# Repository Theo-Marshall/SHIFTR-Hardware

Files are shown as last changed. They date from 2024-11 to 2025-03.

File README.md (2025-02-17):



# SHIFTR 
A BLE to Direct Connect bridge for bike trainers using a WT32-ETH01 module based on ESP32. Increases connection stability and additionally adding Zwift "virtual shifting" functionality to any device supporting FE-C over BLE. Also adding FTMS emulation via DirCon for non-FE-C compatible software like MyWhoosh.

Currently tested with Garmin/Tacx NEO 2T and Vortex but should also work on other trainers supporting FE-C over BLE.

Tested bike trainer software so far:
- &#x2611; Zwift (Pass-through + virtual shifting mode)
- &#x2611; MyWhoosh (Pass-through mode only / TACX Neo 2T and Vortex only with FTMS emulation enabled) 

Disclaimer: Even if everything is working fine this project is still work in progress. Feel free to provide feedback if you encounter any issues.

## Overview
Bike trainers heavily evolved over the last few years. Tacx (acquired by Garmin some years ago) is one of the market leaders producing bike trainers of a very high quality with special features like e.g. "Road Feeling" to simulate different road surfaces. 
Other vendors like Zwift came up with cool new features like "virtual shifting" using the "Zwift Cog" and a controller device (Zwift Click/Play) to have a non-mechanical shifting solution which is setting the gears via software that adjusts the resistance in the trainer. 
Wahoo came up with a technology called "Direct Connect" that allows the trainer devices to be connected via Ethernet (or even WiFi) instead of bluetooth to have a more stable connection.

While other vendors like e.g. Elite or JetBlack are very fast in implementing things like virtual shifting to their newer models Garmin is very slow and unresponsive when it comes to such feature requests. Probably also because they have their own ecosystem that competes with Zwift. 

Using Zwift for many years and owning a "Tacx Vortex" and a "Tacx Neo 2T" bike trainer I have been jealous of features like virtual shifting and the possibility to connect the trainer device via ethernet. So the idea for this project, SHIFTR, was born by having a device between Zwift and the Tacx supporting all this cool new functionality.

After many days and nights of searching the internet for a specification of the protocols I was only able to find small parts for "Direct Connect" that have already been reverse engineered by Roberto Viola in his [QDomyos-Zwift](https://github.com/cagnulein/qdomyos-zwift) project. The code helped me a lot to understand the protocol.
Unfortunately there was absolutely no information about the "virtual shifting" to be found. So a very long session of decompiling Zwift apps and sniffing BLE traffic between Zwift and capable trainers (which fortunately a friend had one of) started. It took some weeks but I was able to reverse engineer the used protocols.

As I wanted to have a convenient solution that doesn't require a special program or app to be started to have that functionality I decided to implement everything on an ESP32 microcontroller that already features WiFi and Bluetooth onboard and also optionally ethernet. The perfect module for that was the [WT32-ETH01](https://en.wireless-tag.com/product-item-2.html) module that comes with everything I needed. The device will be placed very close to the trainer in a 3D printed case that also has a place for a step down converter to be able to use the existing power supply from the trainer.

Now I have a great setup with a Garmin/Tacx NEO 2T with a Zwift Cog installed and communicating to Zwift via ethernet while still having the "Road Feeling" feature: 
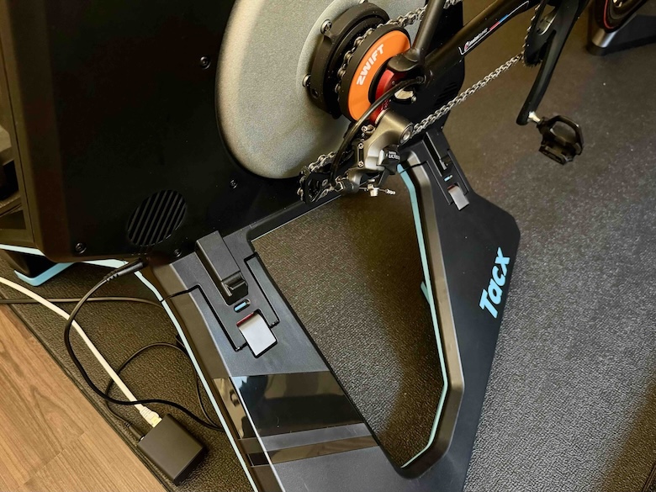
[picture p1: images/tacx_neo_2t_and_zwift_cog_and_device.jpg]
The whole setup


This setup even works great with Zwift running on an Apple TV. Apple TV only supports two simultaneous bluetooth connections and those can now be used for the Zwift Play controllers while the trainer itself is being connected through ethernet.

## How it works
The SHIFTR is working in two modes, "Pass-through" and "Pass-through + virtual shifting":
### Pass-through mode
In this mode the SHIFTR just takes all services from the BLE trainer devices and provides them 1:1 via Direct Connect. It supports SIM and ERG mode as if the device would be connected via bluetooth.
### Pass-through + virtual shifting mode
This mode provides the pass through features as mentioned before and additionally offers a special Zwift service via Direct Connect that allows it to behave like a Zwift certified device offering virtual shifting, too. All necessary information like incline, bicycle and user weight, etc. are transmitted by Zwift and used for calculations. SIM and ERG mode are supported but of course virtual shifting only works in SIM mode.

Details about the virtual shifting function and calculations can be found [here](./VirtualShifting.md).

***Note***: Virtual shifting will be disabled if neither Zwift Play controllers nor a Zwift Click are connected which results in the standard SIM mode with a track resistance of 0%. Then you'd have to shift with your bike but with a Zwift Cog installed this doesn't make sense of course. If the controllers disconnect during a training then the fallback will be this normal SIM mode but as soon as the controller(s) are re-connected the virtual shifting will be enabled again.

### Pass-through + FTMS emulation
This mode provides all services from the BLE trainer and additionally offers a FTMS emulation that internally sends the commands to the BLE FE-C trainer. This makes software like MyWhoosh also working. Doesn't (at least not yet) work with virtual shifting as this is a Zwift-only feature at the moment.

## Needed hardware
- WT32-ETH01 ESP32 board (e.g. from [Amazon](https://www.amazon.de/WT32-ETH01-Embedded-Schnittstelle-Bluetooth-Entwicklungsplatine/dp/B0CW3DDWZ4))
- Step-Down converter 5-80V (the Tacx Neo supplies 48V) to 5V (e.g. from [Amazon](https://www.amazon.de/dp/B0CMC7Y3DJ))
- Y-Splitter for the Tacx power cable (e.g. from [Amazon](https://www.amazon.de/dp/B09FHHN9T5))
- Power connector for the case (e.g. from [Amazon](https://www.amazon.de/gp/product/B09PD6J4BN))
- 3D printed case that fits the WT32-ETH01. Luckily I was able to find a perfect match that also fits the step-down converter: [WT32-ETH01 Enclosure](https://www.thingiverse.com/thing:5621092)
- Two countersunk screws M2x7 to hold the lid on the case

## Hardware installation
- ***IMPORTANT***: Don't solder the pin headers that came with the WT32-ETH01. With the longer pins on the bottom side the module won't fit the case anymore.
- ***IMPORTANT #2***: Connect the step-down converter first to a power supply (e.g. the original one with 48V) and a multimeter and use a screwdriver to adjust the output voltage to 5V before connecting it to the WT32-ETH01 module!
- Use a standard USB<->TTL converter (e.g. with FTDI232 or similar). Make sure that it can provide **3,3V and not 5V** and connect as follows (see also pinout above):
  | Converter | -> | ETH01-EVO | 
  |-|-|-|
  | RX | -> | TXD |
  | TX | -> | RXD |
  | 3V3 | -> | 3V3 |
  | GND | -> | GND |

  It's best to use some breadboard jumper wires that can just be connected without soldering. Use a rubber band to hold them in contact.

  To start the WT32-ETH01 in boot mode it is necessary to connect "IO0" with GND and then to reset the board, shortly connect "EN" to GND for a quarter of a second.

## Software installation
- Open the project in [PlatformIO](https://platformio.org) and let it install the dependencies
- Connect the programmer and upload via the task wt32-eth01 -> Upload and Monitor
- Connect an ethernet cable and make sure a DHCP server exists in your network
- After a few seconds you should be able to see the IP address and the hostname (like e.g. "SHIFTR-123456.local") in the monitor log
- If you don't use the Ethernet interface you can also use the WiFi functionality. For that the device opens an AP with the device name (e.g. "SHIFTR-123456") and the password is the same but of course can be changed later. Please note that WiFi is provided by an external library called [IoTWebConf](https://github.com/prampec/IotWebConf) and is more or less untested
- After that you can configure the device and its network settings in the web interface on e.g. http://SHIFTR-123456.local
- The status page is accessible without credentials, the settings and firmware update pages need the username "admin" and the password is the configured AP password or just the device name (e.g. "SHIFTR-123456") as default. Note that both are case sensitive!
- Further updates can be made over ethernet or WiFi so you can disconnect the programming adapter now

## Finalization
- Finally you can solder some wires to the power connector to the step down module and from there to the WT32-ETH01. Then mount everything in the 3D printed case:

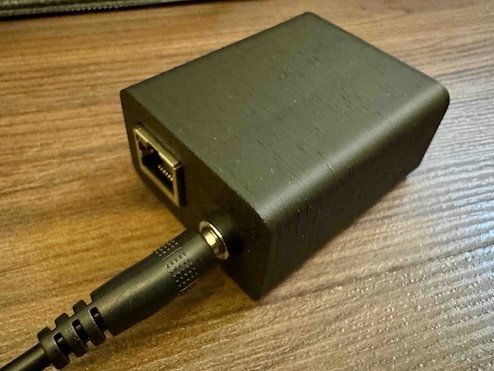
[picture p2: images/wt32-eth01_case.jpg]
Mounted adapter
  

- Use the Y-Power-Splitter to connect the Tacx trainer and the device:
  
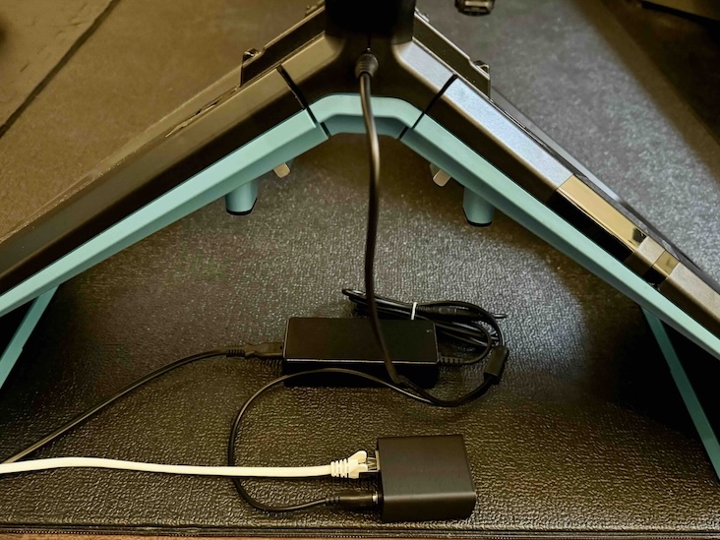
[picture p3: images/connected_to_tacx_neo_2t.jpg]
Connected to Tacx
  

- Power the Trainer and go to the web interface
- Go to "Settings", select the trainer device and "Save"
- Make sure the "Virtual shifting" option is enabled if you want to use it. Virtual shifting only works in Zwift when a Zwift Click or Zwift Play controllers are connected. Otherwise it will fall back to the normal ERG and SIM modes
- In Zwift you need to connect to the "SHIFTR 123456" device instead of your old device now. Have fun!

## Thank you!
You've made it to the end, hopefully you'll have fun rebuilding the whole thing. Please tell me if you like it and if it works as expected.
In case of any questions feel free to contact me!

## Disclaimer
Please always check the documentation of the hardware you bought as there are sometimes small changes in pin assignments, voltage and so on. I don't take any liability for damages or injuries. Build this project at your own risk. The linked products and pages are for reference only. I don't get any money from the manufacturers or the (re)sellers.

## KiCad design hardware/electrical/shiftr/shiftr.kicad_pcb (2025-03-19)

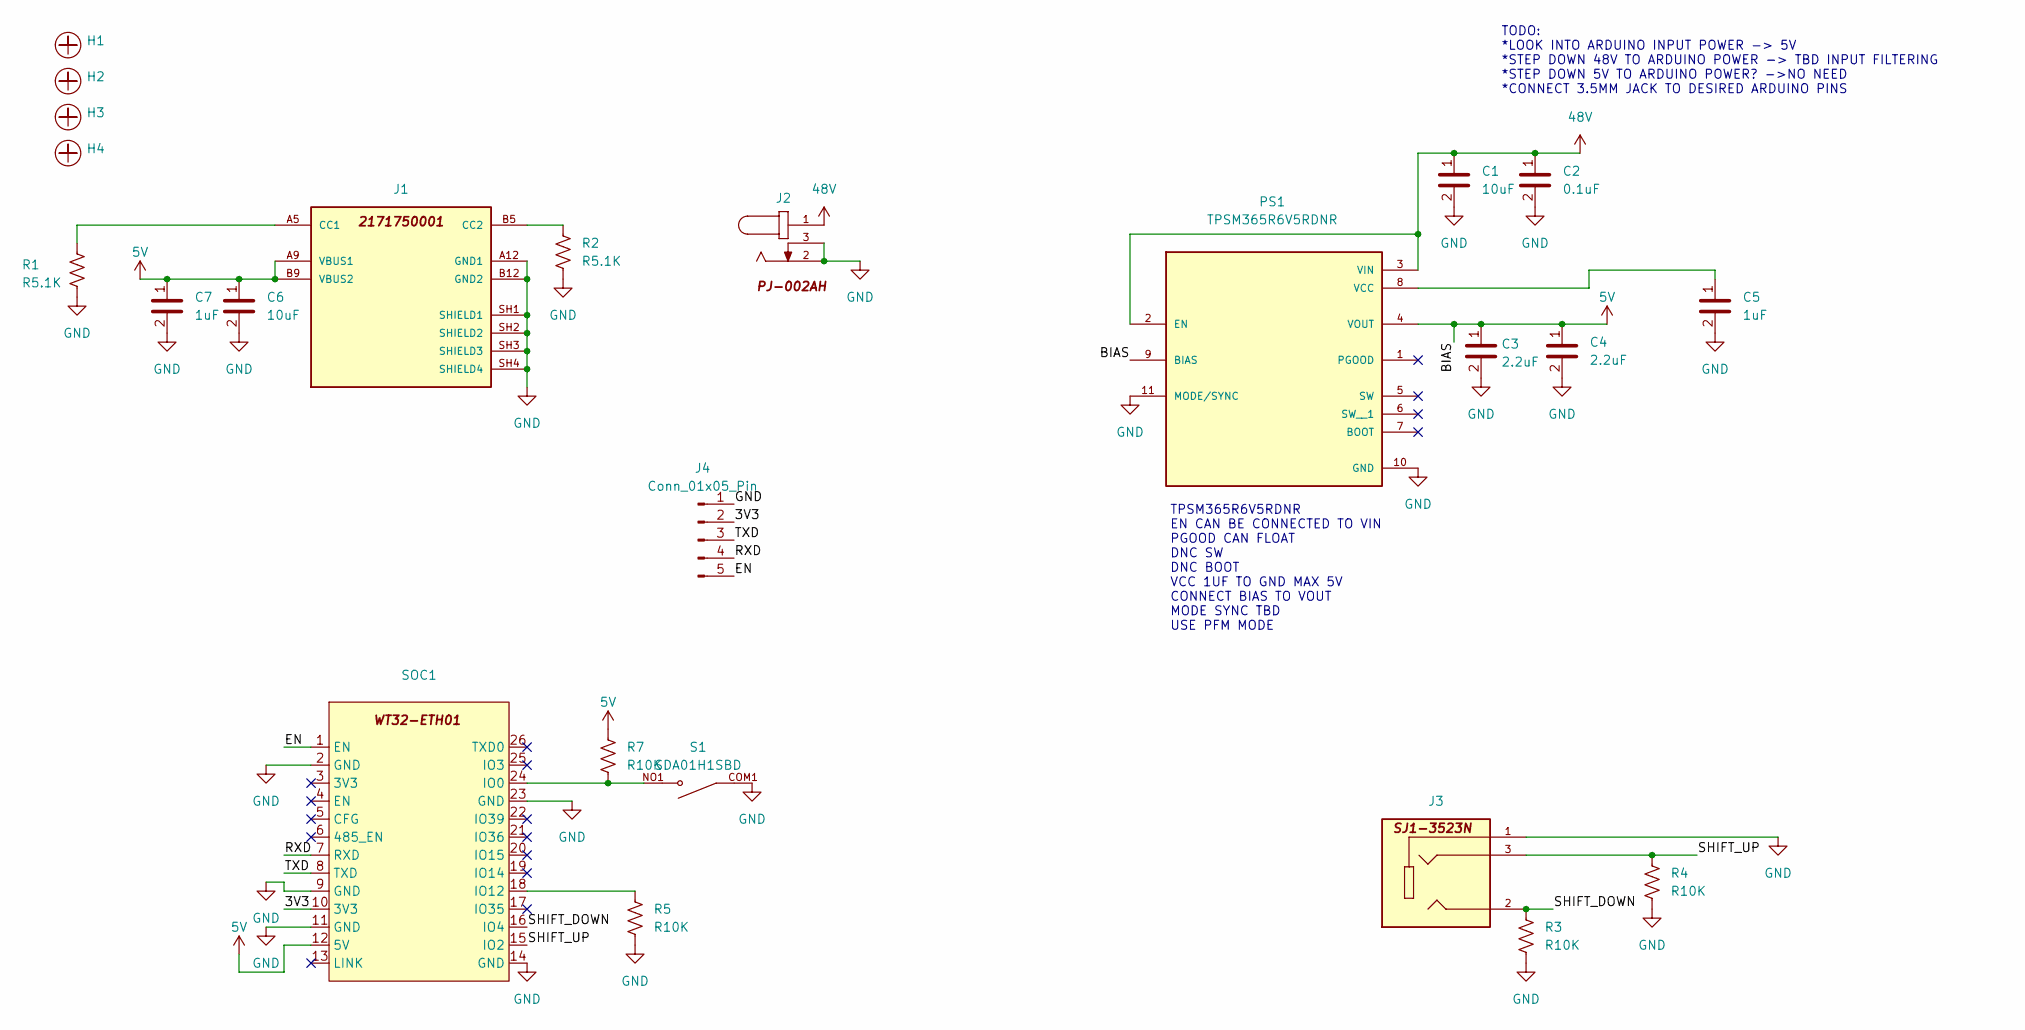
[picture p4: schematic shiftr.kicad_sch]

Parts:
C1, C6: 10uF; C_1210_3225Metric
C2: 0.1uF; C_1210_3225Metric
C3, C4: 2.2uF; C_1210_3225Metric
C5, C7: 1uF; C_0603_1608Metric
H1, H2, H3, H4: Hole-3mm
J1: 2171750001; MOLEX_2171750001; PARTREV A1
J2: PJ-002AH
J3: SJ1-3523N; CUI_SJ1-3523N; PARTREV 1.05
J4: Conn_01x05_Pin; PinHeader_1x05_P2.54mm_Vertical
PS1: TPSM365R6V5RDNR; PARTREV B
R1, R2: R5.1K; R_1206_3216Metric
R3, R4, R5, R7: R10K; R_1206_3216Metric
S1: SDA01H1SBD; SW_SDA01H1SBD; PARTREV 28 may 18
SOC1: WT32-ETH01

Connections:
5V: C3.1, C4.1, C6.1, C7.1, J1.A9 (VBUS1), J1.B9 (VBUS2), PS1.4 (VOUT), PS1.9 (BIAS), R7.1, SOC1.12 (5V)
48V: C1.1, C2.1, J2.1, PS1.2 (EN), PS1.3 (VIN), PS1.3_1, PS1.3_2
/3V3: J4.2, SOC1.10 (3V3)
/EN: J4.5, SOC1.1 (EN)
/RXD: J4.4, SOC1.7 (RXD)
/SHIFT_DOWN: J3.2, R3.1, SOC1.16 (IO4)
/SHIFT_UP: J3.3, R4.1, SOC1.15 (IO2)
/TXD: J4.3, SOC1.8 (TXD)
GND: C1.2, C2.2, C3.2, C4.2, C5.2, C6.2, C7.2, J1.A12 (GND1), J1.B12 (GND2), J1.SH1 (SHIELD1), J1.SH2 (SHIELD2), J1.SH3 (SHIELD3), J1.SH4 (SHIELD4), J2.2, J2.3, J3.1, J4.1, PS1.10 (GND), PS1.11 (MODE/SYNC), R1.2, R2.2, R3.2, R4.2, R5.2, S1.COM1, SOC1.2 (GND), SOC1.9 (GND), SOC1.11 (GND), SOC1.14 (GND), SOC1.23 (GND)
unnamed: J1.A5 (CC1), R1.1
unnamed: J1.B5 (CC2), R2.1
unnamed: C5.1, PS1.8 (VCC)
unnamed: R7.2, S1.NO1, SOC1.24 (IO0)
unnamed: R5.1, SOC1.18 (IO12)

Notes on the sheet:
TODO: *LOOK INTO ARDUINO INPUT POWER -> 5V *STEP DOWN 48V TO ARDUINO POWER -> TBD INPUT FILTERING *STEP DOWN 5V TO ARDUINO POWER? ->NO NEED *CONNECT 3.5MM JACK TO DESIRED ARDUINO PINS
TPSM365R6V5RDNR EN CAN BE CONNECTED TO VIN PGOOD CAN FLOAT DNC SW DNC BOOT VCC 1UF TO GND MAX 5V CONNECT BIAS TO VOUT MODE SYNC TBD USE PFM MODE

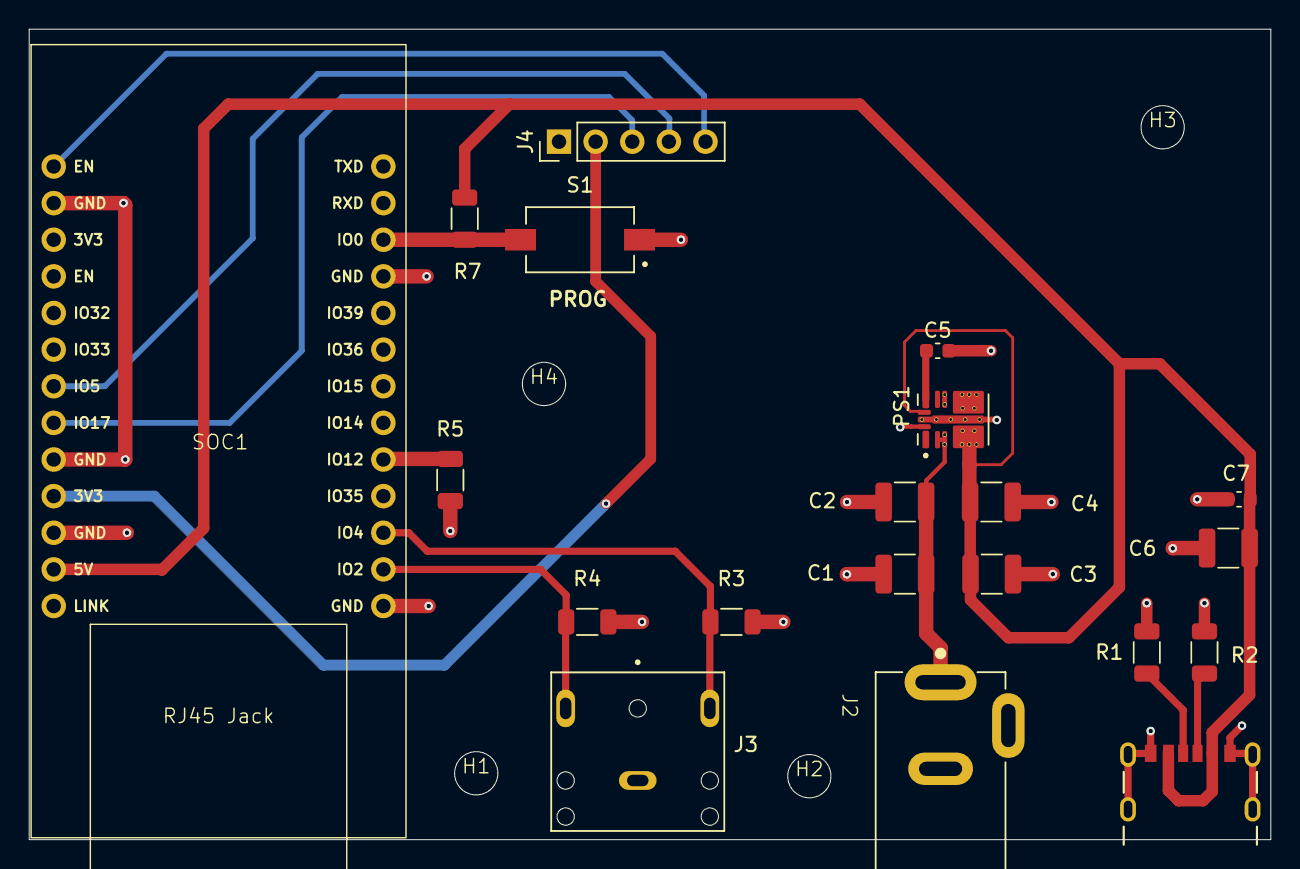
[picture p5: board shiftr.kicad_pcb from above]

Board: 2 copper layers, 86.1 x 56.2 mm, 24 parts (0 on the bottom side), 14 nets.

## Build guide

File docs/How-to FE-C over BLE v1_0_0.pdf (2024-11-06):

# FE-C over BLE

# Simple how-to for engineers

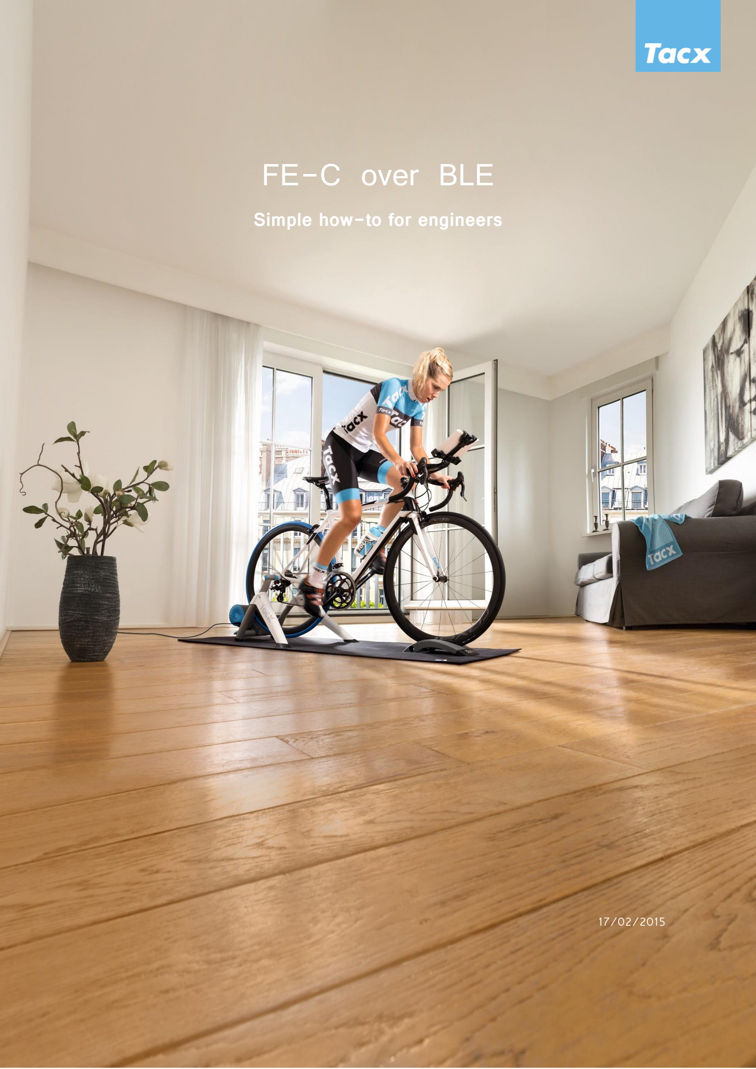
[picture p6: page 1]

1 | 17/02/2015 | FE-C over BLE

17/02/2015

# Introduction

This document will explain how to use the FE-C over BLE feature in Tacx Smart Trainers. Tacx designed this feature because Bluetooth is lacking open standard for trainers on Bluetooth.

It uses the ANT+ FE-C definition for the data content, but transports this data thru a BLE serial port service. Therefore a prerequisite for this technic is knowledge of the ANT+ FE-C protocol. A complete description of FE-C can be found at: http://www.thisisant.com/resources/fitness-equipment-device/

Revision | Effective Date | Author | Description
1.0.0 | 20-8-2015 | D. de Nijs | Initial release.

# Nordic Serialport Service

The transport method that is used is derived from the NordicUartService. This serial port service can basically send and receive arrays of data ranging from 1..20 bytes.

The only thing that is different is the service UUID and the two characteristics UUID’s these are renamed to the Tacx standard UUID with the specific part for the FEC service starting 0xFEC…

In the figure below the UUID’s are shown in there hierarchy order.

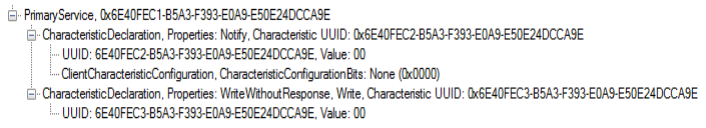
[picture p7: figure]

The 6E40-FEC2-B5A3-F393-E0A9-E50E24DCCA9E is the RX part of the service this characteristic will notify is the trainer sends out an packet(Notification must be turned on in the CharacteristicConfigurationBits).

Characteristic 6E40-FEC2-B5A3-F393-E0A9-E50E24DCCA9E is the TX part of the service, message that need to be send to the trainer can be written to this characteristic. The Ant+ FE-C wound exceed the 20 byte maximum , so there is no need to split message up in multiple sections.

The recommended rate of transmitting messages to the trainer is 4Hz since this is also the native rate over ANT. The trainer will also transmit messages with this rate.

# Datacontent FE-C

The data that is generated by the trainer, and the data that is send to the trainer consists of a complete ANT message.

An example of a message from the trainer can look like this:

A4094E05101904000000FF30

When the data broken up into hex values and interpreted as an ANT message it looks like this:

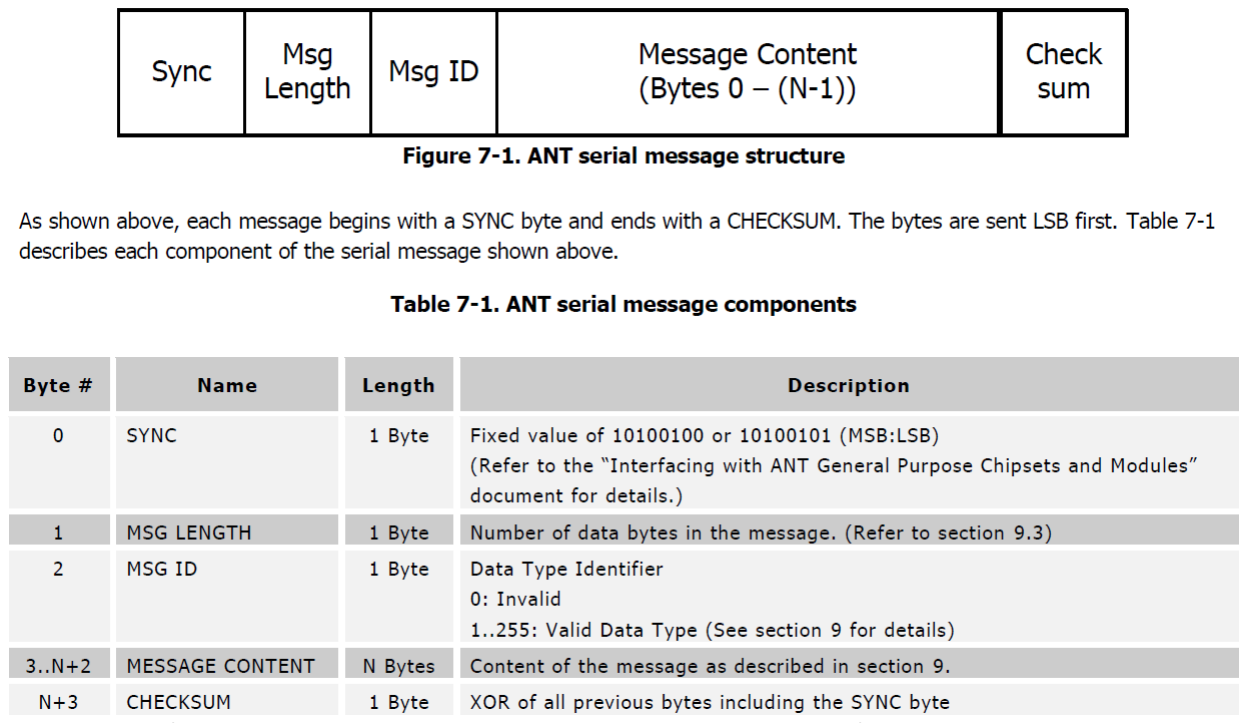
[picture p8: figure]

Section from document: ANT_Message_Protocol_and_Usage_Rev5.0.pdf

Example:

0xA4 | 0x09 | 0x4E | 0x05 | 0x10 0x19 0x04 0x00 0x00 0x00 0xFF 0x24 | 0x30
Sync | Length | Type | Channel | Data | Checksum
This message is a General FE Data page

The message will always start with 0xA4 this is the ANT sync character, followed by the length of the data + 1. The type can vary i.e acknowledged, broadcast.

The channel number is our case channel 5 but the channel number is ignored when a message is send to the trainer.

The channel number is followed by (length-1) data bytes, the message end with a checksum which is the sum of all bytes excluding the 0xA4 sync byte.

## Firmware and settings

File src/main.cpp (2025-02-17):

#include <Arduino.h>
#include <AsyncTCP.h>
#include <BTDeviceManager.h>
#include <Config.h>
#include <DirConManager.h>
#include <ESPmDNS.h>
#include <ETH.h>
#include <IotWebConf.h>
#include <IotWebConfESP32HTTPUpdateServer.h>
#include <IotWebConfUsing.h>
#include <NimBLEDevice.h>
#include <SettingsManager.h>
#include <UUIDs.h>
#include <Utils.h>
#include <Version.h>
#include <WiFi.h>

void networkEvent(WiFiEvent_t event);
void handleWebServerFile(const String& fileName);
void handleWebServerStatus();
void handleWebServerSettings();
void handleWebServerSettingsPost();
void handleWebServerDebug();

bool isMDNSStarted = false;
bool isBLEConnected = false;
bool isEthernetConnected = false;
bool isWiFiConnected = false;

DNSServer dnsServer;
WebServer webServer(WEB_SERVER_PORT);
HTTPUpdateServer updateServer;
IotWebConf iotWebConf(Utils::getHostName().c_str(), &dnsServer, &webServer, Utils::getHostName().c_str(), WIFI_CONFIG_VERSION);

ServiceManager serviceManager;

void setup() {
  log_i(DEVICE_NAME_PREFIX " " VERSION " starting...");
  log_i("Device name: %s, host name: %s", Utils::getDeviceName().c_str(), Utils::getFQDN().c_str());

  // initialize bluetooth device manager
  BTDeviceManager::setLocalDeviceName(Utils::getDeviceName());
  BTDeviceManager::setServiceManager(&serviceManager);
  if (!BTDeviceManager::start()) {
    log_e("Startup failed: Unable to start bluetooth device manager");
    ESP.restart();
  }
  log_i("Bluetooth device manager initialized");

  // initialize network events
  WiFi.onEvent(networkEvent);
  log_i("Network events initialized");

  // initialize ethernet interface
  ETH.begin();
  log_i("Ethernet interface initialized");

  // initialize settings manager
  SettingsManager::initialize(&iotWebConf);

  // initialize wifi manager and web server
  iotWebConf.setStatusPin(WIFI_STATUS_PIN);
  iotWebConf.setConfigPin(WIFI_CONFIG_PIN);
  iotWebConf.addParameterGroup(SettingsManager::getIoTWebConfSettingsParameterGroup());
  iotWebConf.setupUpdateServer(
      [](const char* updatePath) { updateServer.setup(&webServer, updatePath, SettingsManager::getUsername().c_str(), SettingsManager::getAPPassword().c_str()); },
      [](const char* userName, char* password) { updateServer.updateCredentials(userName, password); });
  iotWebConf.init();

  // workaround for missing thing name
  strncpy(iotWebConf.getThingNameParameter()->valueBuffer, Utils::getHostName().c_str(), iotWebConf.getThingNameParameter()->getLength());

  webServer.on("/debug", handleWebServerDebug);
  webServer.on("/status", handleWebServerStatus);
  webServer.on("/favicon.ico", [] { handleWebServerFile("favicon.ico"); });
  webServer.on("/style.css", [] { handleWebServerFile("style.css"); });
  webServer.on("/", [] { handleWebServerFile("index.html"); });
  webServer.on("/settings", HTTP_GET, [] { 
    if (!webServer.authenticate(SettingsManager::getUsername().c_str(), SettingsManager::getAPPassword().c_str())) {
      return webServer.requestAuthentication();
    }
    handleWebServerFile("settings.html"); });
  webServer.on("/settings", HTTP_POST, [] { 
    if (!webServer.authenticate(SettingsManager::getUsername().c_str(), SettingsManager::getAPPassword().c_str())) {
      return webServer.requestAuthentication();
    }
    handleWebServerSettingsPost(); });
  webServer.on("/devicesettings", [] { 
    if (!webServer.authenticate(SettingsManager::getUsername().c_str(), SettingsManager::getAPPassword().c_str())) {
      return webServer.requestAuthentication();
    }
    handleWebServerSettings(); });
  webServer.on("/config", [] { 
    if (!webServer.authenticate(SettingsManager::getUsername().c_str(), SettingsManager::getAPPassword().c_str())) {
      return webServer.requestAuthentication();
    }
    iotWebConf.handleConfig(); });
  
  webServer.onNotFound([]() { iotWebConf.handleNotFound(); });
  log_i("WiFi manager and web server initialized");

  // initialize service manager internal service if enabled
  if (SettingsManager::isVirtualShiftingEnabled()) {
    Service* zwiftCustomService = new Service(NimBLEUUID(ZWIFT_CUSTOM_SERVICE_UUID), true, true);
    zwiftCustomService->addCharacteristic(new Characteristic(NimBLEUUID(ZWIFT_ASYNC_CHARACTERISTIC_UUID), NOTIFY));
    zwiftCustomService->addCharacteristic(new Characteristic(NimBLEUUID(ZWIFT_SYNCRX_CHARACTERISTIC_UUID), WRITE));
    zwiftCustomService->addCharacteristic(new Characteristic(NimBLEUUID(ZWIFT_SYNCTX_CHARACTERISTIC_UUID), INDICATE));
    serviceManager.addService(zwiftCustomService);
  }

  // initialize service manager FTMS service if enabled
  if (SettingsManager::isFTMSEnabled()) {
    Service* fitnessMachineService = new Service(NimBLEUUID(FITNESS_MACHINE_SERVICE_UUID), true, true);
    fitnessMachineService->addCharacteristic(new Characteristic(NimBLEUUID(FITNESS_MACHINE_FEATURE_CHARACTERISTIC_UUID), READ));
    fitnessMachineService->addCharacteristic(new Characteristic(NimBLEUUID(INDOOR_BIKE_DATA_CHARACTERISTIC_UUID), NOTIFY));
    fitnessMachineService->addCharacteristic(new Characteristic(NimBLEUUID(TRAINING_STATUS_CHARACTERISTIC_UUID), READ | NOTIFY));
    fitnessMachineService->addCharacteristic(new Characteristic(NimBLEUUID(FITNESS_MACHINE_CONTROL_POINT_CHARACTERISTIC_UUID), WRITE | INDICATE));
    fitnessMachineService->addCharacteristic(new Characteristic(NimBLEUUID(FITNESS_MACHINE_STATUS_CHARACTERISTIC_UUID), NOTIFY));
    serviceManager.addService(fitnessMachineService);
  }
  log_i("Service manager initialized");

  // set BTDeviceManager selected trainer device
  BTDeviceManager::setRemoteDeviceNameFilter(SettingsManager::getTrainerDeviceName());

  // initialize MDNS
  if (!MDNS.begin(Utils::getHostName().c_str())) {
    log_e("Startup failed: Unable to start MDNS");
    ESP.restart();
  }
  MDNS.setInstanceName(Utils::getDeviceName().c_str());
  isMDNSStarted = true;
  log_i("MDNS initialized");

  // initialize DirCon manager
  DirConManager::setServiceManager(&serviceManager);
  if (!DirConManager::start()) {
    log_e("Startup failed: Unable to start DirCon manager");
    ESP.restart();
  }
  log_i("DirCon Manager initialized");

  log_i("Startup finished");
}

void loop() {
  BTDeviceManager::update();
  DirConManager::update();
  iotWebConf.doLoop();
}

void networkEvent(WiFiEvent_t event) {
  switch (event) {
    case ARDUINO_EVENT_ETH_START:
      log_d("Ethernet started");
      ETH.setHostname(Utils::getHostName().c_str());
      break;
    case ARDUINO_EVENT_ETH_CONNECTED:
      log_i("Ethernet connected");
      break;
    case ARDUINO_EVENT_ETH_GOT_IP:
      log_i("Ethernet DHCP successful with IP %u.%u.%u.%u", ETH.localIP()[0], ETH.localIP()[1], ETH.localIP()[2], ETH.localIP()[3]);
      isEthernetConnected = true;
      break;
    case ARDUINO_EVENT_ETH_DISCONNECTED:
      log_i("Ethernet disconnected");
      isEthernetConnected = false;
      break;
    case ARDUINO_EVENT_ETH_STOP:
      log_d("Ethernet stopped");
      isEthernetConnected = false;
      break;
    case ARDUINO_EVENT_WIFI_STA_GOT_IP:
      log_i("WiFi DHCP successful with IP %u.%u.%u.%u", WiFi.localIP()[0], WiFi.localIP()[1], WiFi.localIP()[2], WiFi.localIP()[3]);
      isWiFiConnected = true;
      break;
    case ARDUINO_EVENT_WIFI_STA_DISCONNECTED:
      log_i("WiFi disconnected");
      isWiFiConnected = false;
      break;
    case ARDUINO_EVENT_WIFI_STA_STOP:
      log_d("WiFi stopped");
      isWiFiConnected = false;
      break;
    default:
      break;
  }
}

extern const uint8_t favicon_ico_start[] asm("_binary_src_web_favicon_ico_start");
extern const uint8_t favicon_ico_end[] asm("_binary_src_web_favicon_ico_end");

extern const uint8_t index_html_start[] asm("_binary_src_web_index_html_start");
extern const uint8_t index_html_end[] asm("_binary_src_web_index_html_end");

extern const uint8_t settings_html_start[] asm("_binary_src_web_settings_html_start");
extern const uint8_t settings_html_end[] asm("_binary_src_web_settings_html_end");

extern const uint8_t style_css_start[] asm("_binary_src_web_style_css_start");
extern const uint8_t style_css_end[] asm("_binary_src_web_style_css_end");

void handleWebServerFile(const String& fileName) {
  if (iotWebConf.handleCaptivePortal()) {
    return;
  }

  if (fileName.equals("index.html")) {
    webServer.send_P(200, "text/html", (char*)index_html_start, (index_html_end - index_html_start));
  }
  if (fileName.equals("settings.html")) {
    webServer.send_P(200, "text/html", (char*)settings_html_start, (settings_html_end - settings_html_start));
  }
  if (fileName.equals("style.css")) {
    webServer.send_P(200, "text/css", (char*)style_css_start, (style_css_end - style_css_start));
  }
  if (fileName.equals("favicon.ico")) {
    webServer.send_P(200, "image/x-icon", (char*)favicon_ico_start, (favicon_ico_end - favicon_ico_start));
  }
}

void handleWebServerSettings() {
  String json = "{";
  json += "\"device_name\": \"";
  json += Utils::getDeviceName().c_str();
  json += "\",";

  json += "\"trainer_device\": \"";
  json += SettingsManager::getTrainerDeviceName().c_str();
  json += "\",";

  String devices_json = "\"trainer_devices\": [";
  devices_json += "\"\",";
  for (size_t deviceIndex = 0; deviceIndex < BTDeviceManager::getScannedDevices()->size(); deviceIndex++) {
    if (BTDeviceManager::getScannedDevices()->at(deviceIndex).haveName()) {
      devices_json += "\"";
      devices_json += BTDeviceManager::getScannedDevices()->at(deviceIndex).getName().c_str();
      devices_json += "\",";
    }
  }

  if (devices_json.endsWith(",")) {
    devices_json.remove(devices_json.length() - 1);
  }
  devices_json += "],";

  json += devices_json;

  json += "\"virtual_shifting\": ";
  if (SettingsManager::isVirtualShiftingEnabled()) {
    json += "true";
  } else {
    json += "false";
  }
  json += ",";

  json += "\"virtual_shifting_mode\": ";
  json += SettingsManager::getVirtualShiftingMode();
  json += ",";

  std::map<size_t, std::string> modes = SettingsManager::getVirtualShiftingModes();
  String modes_json = "\"virtual_shifting_modes\": [";
  for (auto mode = modes.begin(); mode != modes.end(); mode++) {
      modes_json += "{\"name\": \"";
      modes_json += mode->second.c_str();
      modes_json += "\", \"value\": ";
      modes_json += mode->first;
      modes_json += "},";
  }
  if (modes_json.endsWith(",")) {
    modes_json.remove(modes_json.length() - 1);
  }
  modes_json += "],";

  json += modes_json;

  json += "\"chainring_teeth\": ";
  json += SettingsManager::getChainringTeeth();
  json += ",";

  json += "\"sprocket_teeth\": ";
  json += SettingsManager::getSprocketTeeth();
  json += ",";

  json += "\"grade_smoothing\": ";
  if (SettingsManager::isGradeSmoothingEnabled()) {
    json += "true";
  } else {
    json += "false";
  }
  json += ",";

  json += "\"difficulty\": ";
  json += SettingsManager::getDifficulty();
  json += ",";
  
  json += "\"ftms_emulation\": ";
  if (SettingsManager::isFTMSEnabled()) {
    json += "true";
  } else {
    json += "false";
  }
  json += "";

  json += "}";

  webServer.send(200, "application/json", json);
}

void handleWebServerSettingsPost() {
  if (webServer.args() > 0) {
    if (webServer.hasArg("trainer_device")) {
      SettingsManager::setTrainerDeviceName(webServer.arg("trainer_device").c_str());
    }
    if (webServer.hasArg("virtual_shifting")) {
      SettingsManager::setVirtualShiftingEnabled(true);
    } else {
      SettingsManager::setVirtualShiftingEnabled(false);
    }
    if (webServer.hasArg("virtual_shifting_mode")) {
      SettingsManager::setVirtualShiftingMode((VirtualShiftingMode)std::atoi(webServer.arg("virtual_shifting_mode").c_str()));
    }
    if (webServer.hasArg("chainring_teeth")) {
      SettingsManager::setChainringTeeth(std::atoi(webServer.arg("chainring_teeth").c_str()));
    }
    if (webServer.hasArg("sprocket_teeth")) {
      SettingsManager::setSprocketTeeth(std::atoi(webServer.arg("sprocket_teeth").c_str()));
    }
    if (webServer.hasArg("grade_smoothing")) {
      SettingsManager::setGradeSmoothingEnabled(true);
    } else {
      SettingsManager::setGradeSmoothingEnabled(false);
    }
    if (webServer.hasArg("difficulty")) {
      SettingsManager::setDifficulty(std::atoi(webServer.arg("difficulty").c_str()));
    }
    if (webServer.hasArg("ftms_emulation")) {
      SettingsManager::setFTMSEnabled(true);
      SettingsManager::setVirtualShiftingEnabled(false);
    } else {
      SettingsManager::setFTMSEnabled(false);
    }
    iotWebConf.saveConfig();
    delay(500);
    ESP.restart();
  }
}

void handleWebServerStatus() {
  String json = "{";
  json += "\"device_name\": \"";
  json += Utils::getDeviceName().c_str();
  json += "\",";

  json += "\"version\": \"";
  json += VERSION;
  json += "\",";

  json += "\"build_timestamp\": \"";
  json += VERSION_TIMESTAMP;
  json += "\",";

  json += "\"hostname\": \"";
  json += Utils::getFQDN().c_str();
  json += "\",";

  json += "\"ethernet_status\": \"";
  if (isEthernetConnected) {
    json += "Connected";
    json += ", IP: ";
    json += ETH.localIP().toString();
  } else {
    json += "Not connected";
  }
  json += "\",";

  json += "\"wifi_status\": \"";
  switch (iotWebConf.getState()) {
    case iotwebconf::NetworkState::ApMode:
      json += "Access-Point mode";
      break;
    case iotwebconf::NetworkState::Boot:
      json += "Booting";
      break;
    case iotwebconf::NetworkState::Connecting:
      json += "Connecting";
      break;
    case iotwebconf::NetworkState::NotConfigured:
      json += "Not configured";
      break;
    case iotwebconf::NetworkState::OffLine:
      json += "Disconnected";
      break;
    case iotwebconf::NetworkState::OnLine:
      json += "Connected";
      json += ", SSID: ";
      json += WiFi.SSID();
      json += ", IP: ";
      json += WiFi.localIP().toString();
      break;
    default:
      json += "Unknown";
      break;
  }
  json += "\",";

  json += "\"service_status\": \"";
  json += serviceManager.getStatusMessage().c_str();
  json += "\",";

  json += "\"dircon_status\": \"";
  json += DirConManager::getStatusMessage().c_str();
  json += "\",";

  json += "\"ble_status\": \"";
  json += BTDeviceManager::getStatusMessage().c_str();
  json += "\",";

  json += "\"mode\": \"";
  json += "Pass-through";
  if (SettingsManager::isFTMSEnabled()) {
    json += " + FTMS emulation";
  }
  if (SettingsManager::isVirtualShiftingEnabled()) {
    json += " + virtual shifting";
  }
  json += "\",";

  json += "\"free_heap\": ";
  json += ESP.getFreeHeap();
  json += "}";

  webServer.send(200, "application/json", json);
}

void handleWebServerDebug() {

  String json = "{";
  json += "\"zwift_trainer_mode\": \"";
  switch (DirConManager::getZwiftTrainerMode()) {
    case TrainerMode::SIM_MODE:
      json += "SIM mode";
      break;
    case TrainerMode::SIM_MODE_VIRTUAL_SHIFTING:
      json += "SIM + VS mode";
      break;
    default:
      json += "ERG mode";
      break;
  }
  json += "\",";

  String services_json = "\"ble_services\": {";
  for (Service* service : serviceManager.getServices()) {
    services_json += "\"";
    services_json += service->UUID.to128().toString().c_str();
    services_json += "\": {";
    for (Characteristic* characteristic : service->getCharacteristics()) {
      services_json += "\"";
      services_json += characteristic->UUID.to128().toString().c_str();
      services_json += "\": ";
      services_json += characteristic->getSubscriptions().size();
      services_json += ",";
    }
    if (services_json.endsWith(",")) {
      services_json.remove(services_json.length() - 1);
    }
    services_json += "},";
  }
  if (services_json.endsWith(",")) {
    services_json.remove(services_json.length() - 1);
  }
  services_json += "}";

  json += services_json;

  json += "}";

  webServer.send(200, "application/json", json);
}

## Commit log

2024-10-21 fix: repair service advertising and handling
    [main.cpp]
2024-11-06 feat(web): add device settings page
2024-11-13 feat: use power and cadence from FE-C
2024-11-15 feat: add gear ratio to settings, add new resistance calculation
2024-11-16 fix: use gear ratio in reverse calculations
2024-11-16 fix: correct calculation mistake, make track resistance not default
2024-11-17 feat: add target power virtual shifting mode
2024-11-17 feat: add internal speed calculation, check power underrun
2024-11-18 feat: make "target power" mode the default
2024-12-07 feat(targetpower): use different calculation in target power mode
2025-02-06 fix: revert change for calculation in target power mode
2025-02-06 fix: add default gear ratio in target power mode
2025-02-15 fix: correct usage of speed and resistances in calculations
2025-02-16 feat: make basic resistance mode the default
2025-02-16 fix(targetpower): use physical gear ratio for speed and power calculation
2025-02-27 add electrical project, ignore backups
    [shiftr.kicad_pcb, shiftr.kicad_sch]
2025-02-27 add WT32-ETH01 footprint"
2025-03-04 add wth symbol to schematic
    [shiftr.kicad_sch]
2025-03-04 add barrel connector to sch and pcb lib
2025-03-04 add audio jack sch and pcb
    [shiftr.kicad_sch]
2025-03-04 add usb c connector sch and pcb lib
    [shiftr.kicad_sch]
2025-03-04 add 5.1kohm resistor sch
    [shiftr.kicad_pcb, shiftr.kicad_sch]
2025-03-08 flesh out more of the 48v->5v conversion
    [shiftr.kicad_pcb, shiftr.kicad_sch]
2025-03-14 add shift button nets, pull down resistors
    [shiftr.kicad_pcb, shiftr.kicad_sch]
2025-03-14 route traces
    [shiftr.kicad_pcb, shiftr.kicad_sch]
2025-03-16 finish up routing, wt32 now on headers
    [shiftr.kicad_pcb]
2025-03-16 add programming pinheader
    [shiftr.kicad_pcb, shiftr.kicad_sch]
2025-03-19 update some traces
    [shiftr.kicad_pcb, shiftr.kicad_sch]

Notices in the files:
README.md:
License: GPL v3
